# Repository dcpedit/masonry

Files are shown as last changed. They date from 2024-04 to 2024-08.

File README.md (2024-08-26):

<p align="center">
  
</p>

# Masonry Keyboard

Inspired by [Bruce the Keyboard](https://www.jlw-kb.com/products/bruce-the-keyboard-the-pcb), this is a 12 column version with a less aggressive stagger.

Schematic for the STM32F072 integration was taken from Sleepdealer's [OSFRL project](https://github.com/Sleepdealr/OSFRL)



Here are the supported layouts:
[Keyboard Layout Editor](http://www.keyboard-layout-editor.com/#/gists/711e40adc1aee2aae4437fc2fe2fa7aa)



## Ordering PCBs from JLCPCB




The files needed for https://jlcpcb.com are located in the production folder:

* `pcb/production`

Once `pcb.zip` has been uploaded, you can continue with the selected default options. You can optionally change the solder mask color, which changes the final color of your PCB.

When using their assembly service, you will need to upload the following files separately:

* `bom.csv`
* `positions.csv`

These files were all generated with Fabrication Toolkit for KiCad: https://github.com/bennymeg/Fabrication-Toolkit

## Stacked Acrylic Case





Case file is in the `assets` folder.

### Parts List
| Description | Qty | Notes |
| --- | --- | ----- |
| 3mm acrylic | 7 | Qty = number of case layers
| 1.5mm acrylic | 1 | Switch plate
| M3x20mm chicago bolt | 6 | [Link](https://www.aliexpress.us/item/2251832451307213.html)
| M3x10mm chicago bolt | 1 | [Link](https://www.aliexpress.us/item/2251832451307213.html)
| M3x6mm screw | 1 - 6 | [Link](https://www.aliexpress.us/item/2255800885711092.html)
| M2x4mm round standoff | 7 | [Link](https://www.aliexpress.us/item/2251832782591461.html)
| M2x3mm screw | 7 | [Link](https://www.aliexpress.us/item/2255800480170108.html)
| M2x4mm screw | 7 | [Link](https://www.aliexpress.us/item/2255800480170108.html)
| 1mm EVA foam | 1 | Case foam
| 1.5mm EVA foam | 1 | Switch plate foam, [link](https://www.aliexpress.us/item/3256804208838525.html)
| 2mm EVA foam | 1 | Switch plate foam
| MX Switch | 38 - 44 |
| Adhesive rubber feet | 4 

Keycap sizes will depend on the layout you're building (refer to KLE layout above).  Blank uniform-profile keycaps works really great for this keyboard since the keys have a vertical orientation.  I found my blank XDA PBT keycaps on AliExpress.  The specific ones I use in my build were purchased [here (1u - 2u)](https://www.aliexpress.us/item/3256804203440964.html) and [here (3u)](https://www.aliexpress.us/item/3256801190573750.html).

| Keycap | Qty |
| --- | --- |
| 1u | 18 - 28
| 1.25u | 8
| 1.5u | 4
| 1.75u | 4
| 2u | 0 - 4
| 3u | 0 - 2

### Assembly

The M3 hardware is for the keyboard case.  The shorter M3 fastener goes above the USB connector.  You will need to use a wafer head (flat) screw on the bottom to keep the port clear for the USB cable.  You can optionally use the same M3x6mm wafer head screws for the entire bottom of the case instad of the chicago bolt ones, which is what I did for my build.

The M2 hardware is to fasten the PCB to the case.  The M2x3mm screws go on the bottom, and the M2x4mm screws go on the top (PCB side), with the M2x4mm standoff extending through the bottom of the case.  The PCB is essentially floating vertically, but is held up by the 1mm case foam.  Below is simple diagram of how everything fits together.



### Firmware

QMK/VIA source:
https://github.com/qmk/qmk_firmware/tree/master/keyboards/dcpedit/masonry

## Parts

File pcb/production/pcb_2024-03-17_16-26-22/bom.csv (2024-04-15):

Designator | Footprint | Quantity | Value | LCSC Part #
C1, C4, C5, C6, C7, C8 | 0402 | 6 | 100nF | C307331
C10, C3, C9 | 0402 | 3 | 1uF | C52923
C2 | 0402 | 1 | 4.7uF | C52923
D1, D10, D11, D12, D13, D14, D15, D16, D17, D18, D19, D2, D20, D21, D22, D23, D24, D25, D26, D27, D28, D29, D3, D30, D31, D32, D33, D34, D35, D36, D37, D38, D39, D4, D40, D41, D42, D43, D44, D5, D6, D7, D8, D9 | D_SOD123 | 44 | 1n4148 | C81598
F1 | 1206 | 1 | 500mA | C70076
H2_7, H2_6, H2_5, H2_4, H2_3, H2_2, H2 |  | 7
J1 | USB_C_Receptacle_HRO_TYPE-C-31-M-12 | 1 | USB_C_Receptacle_USB2.0 | C165948
MX00, MX25, MX45, MX60 | MXOnly-1.75U-Hotswap-Vertical | 4 | ~
MX01, MX02, MX03, MX24, MX42, MX43, MX44, MX61 | MXOnly-1.25U-Hotswap-Vertical | 8 | ~
MX04, MX10, MX11, MX12, MX13, MX14, MX15, MX21, MX22, MX23, MX31, MX32, MX33, MX34, MX41, MX50, MX51, MX52, MX53, MX54, MX55, MX62, MX63, MX64, MX71, MX72, MX73, MX74 | MXOnly-1U-Hotswap | 28 | ~
MX05, MX20, MX40, MX65 | MXOnly-1.5U-Hotswap-Vertical | 4 | ~
MX21.2 | MXOnly-2U-Hotswap-ReversedVerticalStabilizers | 1 | ~
MX33.2, MX72.2 | MXOnly-2U-Hotswap | 2 | ~
MX64.2 | MXOnly-2U-Hotswap-VerticalStabilizers | 1 | ~
R1 | 0402 | 1 | 10k | C25744
R2, R3 | 0402 | 2 | 5k1 | C25905
SW1, SW2 | SW_SPST_SKQG_WithoutStem | 2 | RST | C318884
U1 | SOT-23-6 | 1 | USBLC6-2SC6 | C2827654
U2 | LQFP-48_7x7mm_P0.5mm | 1 | STM32F072C8Tx | C80488
U3 | SOT-23 | 1 | XC6206PxxxMR-Regulator_Linear | C5446

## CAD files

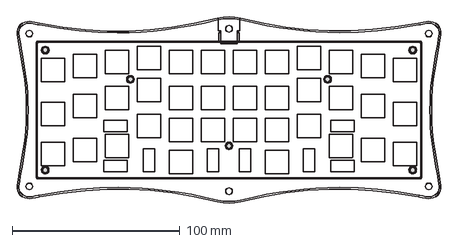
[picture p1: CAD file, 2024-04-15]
assets/case.dxf
253.8 x 111.5 mm

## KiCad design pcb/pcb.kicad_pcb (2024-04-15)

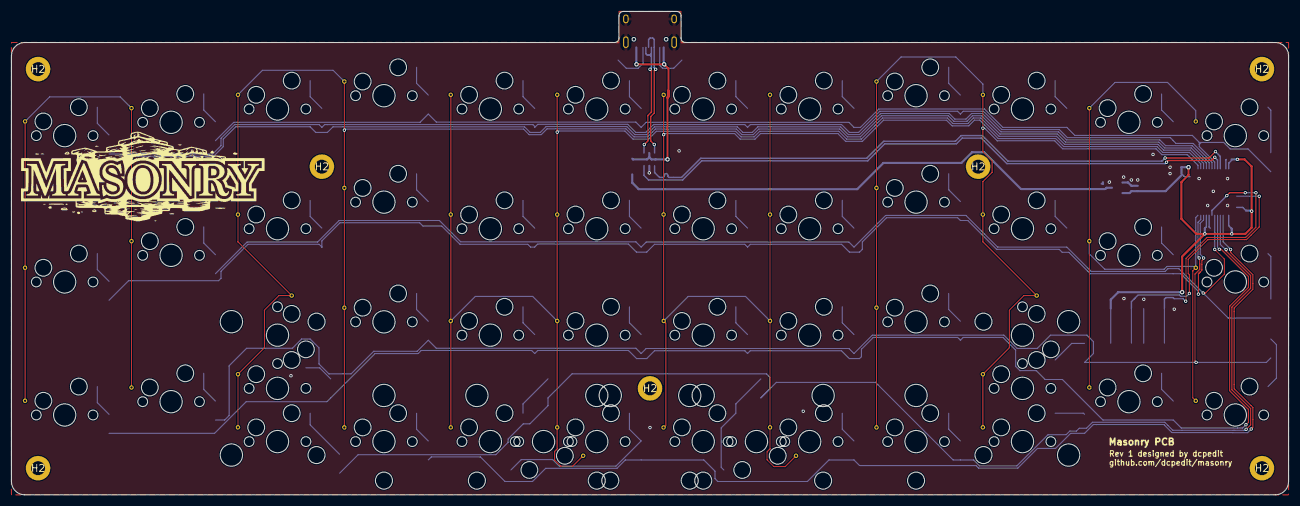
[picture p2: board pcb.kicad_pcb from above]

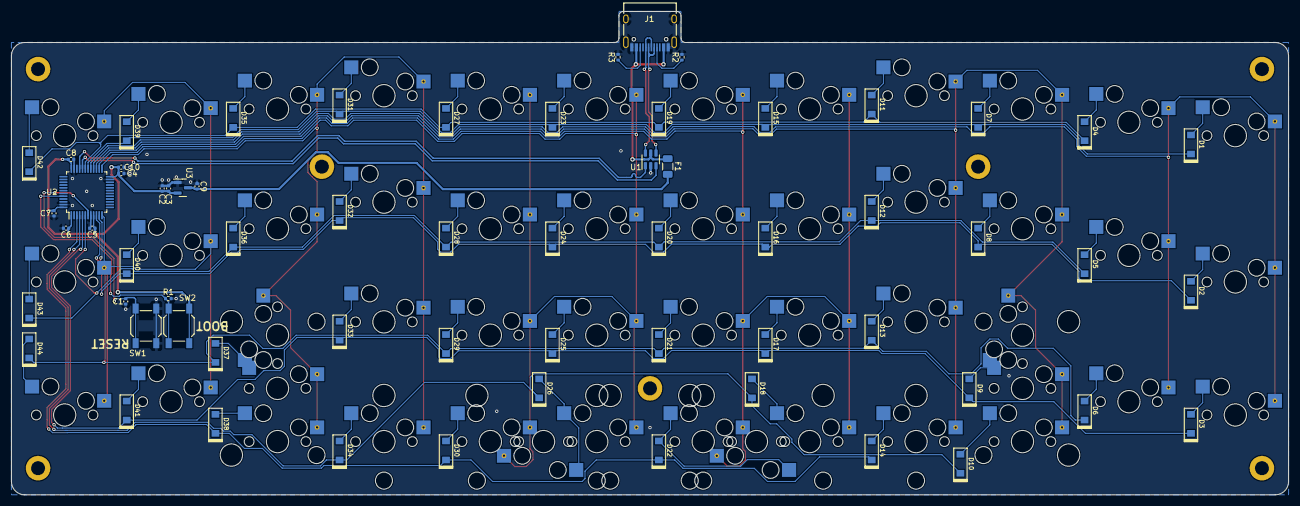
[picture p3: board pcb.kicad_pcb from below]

Board: 2 copper layers, 228.6 x 86.5 mm, 119 parts (64 on the bottom side), 70 nets.

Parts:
C1, C4, C5, C6, C7, C8: 100nF; C_0402_1005Metric
C2: 4.7uF; C_0402_1005Metric
C3, C9, C10: 1uF; C_0402_1005Metric
D1, D2, D3, D4, D5, D6, D7, D8, D9, D10, D11, D12, D13, D14, D15, D16, D17, D18, D19, D20, D21, D22, D23, D24, D25, D26, D27, D28, D29, D30, D31, D32, D33, D34, D35, D36, D37, D38, D39, D40, D41, D42, D43, D44: 1n4148; D_SOD123
F1: 500mA; Fuse_1206_3216Metric
H2, H2#2, H2#3, H2#4, H2#5, H2#6, H2#7: (no value)
J1: USB_C_Receptacle_USB2.0; USB_C_Receptacle_HRO_TYPE-C-31-M-12
MX00, MX25, MX45, MX60: MXOnly-1.75U-Hotswap-Vertical
MX01, MX02, MX03, MX24, MX42, MX43, MX44, MX61: MXOnly-1.25U-Hotswap-Vertical
MX04, MX10, MX11, MX12, MX13, MX14, MX15, MX21, MX22, MX23, MX31, MX32, MX33, MX34, MX41, MX50, MX51, MX52, MX53, MX54, MX55, MX62, MX63, MX64, MX71, MX72, MX73, MX74: MXOnly-1U-Hotswap
MX05, MX20, MX40, MX65: MXOnly-1.5U-Hotswap-Vertical
MX21.2: MXOnly-2U-Hotswap-ReversedVerticalStabilizers
MX33.2, MX72.2: MXOnly-2U-Hotswap
MX64.2: MXOnly-2U-Hotswap-VerticalStabilizers
R1: 10k; R_0402_1005Metric
R2, R3: 5k1; R_0402_1005Metric
SW1, SW2: RST; SW_SPST_SKQG_WithoutStem
U1: USBLC6-2SC6; SOT-23-6
U2: STM32F072C8Tx; LQFP-48_7x7mm_P0.5mm
U3: XC6206PxxxMR-Regulator_Linear; SOT-23

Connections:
+3V3: C2.1, C3.1, C4.1, C5.1, C6.1, C7.1, C8.1, C10.2, SW2.1, U2.1 (VBAT), U2.9 (VDDA), U2.24 (VDD), U2.36 (VDDIO2), U2.48 (VDD), U3.2 (VO)
+5V: C9.2, F1.2, U3.3 (VI)
/CC1: J1.A5 (CC1), R2.1
/CC2: J1.B5 (CC2), R3.1
BOOT0: R1.1, SW2.2, U2.44 (BOOT0)
COL0: MX00.1 (COL), MX10.1 (COL), MX20.1 (COL), MX40.1 (COL), MX50.1 (COL), MX60.1 (COL), U2.29 (PA8)
COL1: MX01.1 (COL), MX11.1 (COL), MX21.1 (COL), MX21.2.1 (COL), MX31.1 (COL), MX41.1 (COL), MX51.1 (COL), MX61.1 (COL), MX71.1 (COL), U2.28 (PB15)
COL2: MX02.1 (COL), MX12.1 (COL), MX22.1 (COL), MX32.1 (COL), MX42.1 (COL), MX52.1 (COL), MX62.1 (COL), MX72.1 (COL), MX72.2.1 (COL), U2.27 (PB14)
COL3: MX03.1 (COL), MX13.1 (COL), MX23.1 (COL), MX33.1 (COL), MX33.2.1 (COL), MX43.1 (COL), MX53.1 (COL), MX63.1 (COL), MX73.1 (COL), U2.26 (PB13)
COL4: MX04.1 (COL), MX14.1 (COL), MX24.1 (COL), MX34.1 (COL), MX44.1 (COL), MX54.1 (COL), MX64.1 (COL), MX64.2.1 (COL), MX74.1 (COL), U2.25 (PB12)
COL5: MX05.1 (COL), MX15.1 (COL), MX25.1 (COL), MX45.1 (COL), MX55.1 (COL), MX65.1 (COL), U2.12 (PA2)
D_N: U1.3 (I/O2), U2.32 (PA11)
D_P: U1.1 (I/O1), U2.33 (PA12)
D_USB_+: J1.A6 (D+), J1.B6 (D+), U1.6 (I/O1)
D_USB_-: J1.A7 (D-), J1.B7 (D-), U1.4 (I/O2)
GND: C1.1, C2.2, C3.2, C4.2, C5.2, C6.2, C7.2, C8.2, C9.1, C10.1, J1.A1 (GND), J1.A12 (GND), J1.B1 (GND), J1.B12 (GND), J1.S1 (SHIELD), R1.2, R2.2, R3.2, SW1.1, U1.2 (GND), U2.8 (VSSA), U2.23 (VSS), U2.35 (VSS), U2.47 (VSS), U3.1 (GND)
NRST: C1.2, SW1.2, U2.7 (NRST)
unnamed: D1.2 (A), MX00.2 (ROW)
unnamed: D2.2 (A), MX10.2 (ROW)
unnamed: D3.2 (A), MX20.2 (ROW)
unnamed: D4.2 (A), MX40.2 (ROW)
unnamed: D5.2 (A), MX50.2 (ROW)
unnamed: D6.2 (A), MX60.2 (ROW)
unnamed: D7.2 (A), MX01.2 (ROW)
unnamed: D8.2 (A), MX11.2 (ROW)
unnamed: D9.2 (A), MX21.2 (ROW), MX21.2.2 (ROW)
unnamed: D10.2 (A), MX31.2 (ROW)
unnamed: D11.2 (A), MX41.2 (ROW)
unnamed: D12.2 (A), MX51.2 (ROW)
unnamed: D13.2 (A), MX61.2 (ROW)
unnamed: D14.2 (A), MX71.2 (ROW)
unnamed: D15.2 (A), MX02.2 (ROW)
unnamed: D16.2 (A), MX12.2 (ROW)
unnamed: D17.2 (A), MX22.2 (ROW)
unnamed: D18.2 (A), MX32.2 (ROW)
unnamed: D19.2 (A), MX42.2 (ROW)
unnamed: D20.2 (A), MX52.2 (ROW)
unnamed: D21.2 (A), MX62.2 (ROW)
unnamed: D22.2 (A), MX72.2 (ROW), MX72.2.2 (ROW)
unnamed: D23.2 (A), MX03.2 (ROW)
unnamed: D24.2 (A), MX13.2 (ROW)
unnamed: D25.2 (A), MX23.2 (ROW)
unnamed: D26.2 (A), MX33.2 (ROW), MX33.2.2 (ROW)
unnamed: D27.2 (A), MX43.2 (ROW)
unnamed: D28.2 (A), MX53.2 (ROW)
unnamed: D29.2 (A), MX63.2 (ROW)
unnamed: D30.2 (A), MX73.2 (ROW)
unnamed: D31.2 (A), MX04.2 (ROW)
unnamed: D32.2 (A), MX14.2 (ROW)
unnamed: D33.2 (A), MX24.2 (ROW)
unnamed: D34.2 (A), MX34.2 (ROW)
unnamed: D35.2 (A), MX44.2 (ROW)
unnamed: D36.2 (A), MX54.2 (ROW)
unnamed: D37.2 (A), MX64.2 (ROW), MX64.2.2 (ROW)
unnamed: D38.2 (A), MX74.2 (ROW)
unnamed: D39.2 (A), MX05.2 (ROW)
unnamed: D40.2 (A), MX15.2 (ROW)
unnamed: D41.2 (A), MX25.2 (ROW)
unnamed: D42.2 (A), MX45.2 (ROW)
unnamed: D43.2 (A), MX55.2 (ROW)
unnamed: D44.2 (A), MX65.2 (ROW)
ROW0: D1.1 (K), D7.1 (K), D15.1 (K), D23.1 (K), D31.1 (K), D39.1 (K), U2.30 (PA9)
ROW1: D2.1 (K), D8.1 (K), D16.1 (K), D24.1 (K), D32.1 (K), D40.1 (K), U2.10 (PA0)
ROW2: D3.1 (K), D9.1 (K), D17.1 (K), D25.1 (K), D33.1 (K), D41.1 (K), U2.5 (PF0)
ROW3: D10.1 (K), D18.1 (K), D26.1 (K), D34.1 (K), U2.4 (PC15)
ROW4: D4.1 (K), D11.1 (K), D19.1 (K), D27.1 (K), D35.1 (K), D42.1 (K), U2.31 (PA10)
ROW5: D5.1 (K), D12.1 (K), D20.1 (K), D28.1 (K), D36.1 (K), D43.1 (K), U2.6 (PF1)
ROW6: D6.1 (K), D13.1 (K), D21.1 (K), D29.1 (K), D37.1 (K), D44.1 (K), U2.11 (PA1)
ROW7: D14.1 (K), D22.1 (K), D30.1 (K), D38.1 (K), U2.3 (PC14)
VBUS: F1.1, J1.A4 (VBUS), J1.A9 (VBUS), J1.B4 (VBUS), J1.B9 (VBUS), U1.5 (VBUS)

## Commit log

2024-04-15 Add proper readme
    [pcb.kicad_pcb]
2024-04-15 Add dxf
    [case.dxf]
